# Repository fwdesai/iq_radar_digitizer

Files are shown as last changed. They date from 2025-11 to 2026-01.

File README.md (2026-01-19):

IQ radar digitizer board for vital signs monitoring

v1
Screenshot 2025-11-26 at 11 20 54 PM

v2
Screenshot 2025-11-26 at 11 20 23 PM

v2 board pictured with K-LC5 mm-wave singled ended module:
FullSizeRender (1)

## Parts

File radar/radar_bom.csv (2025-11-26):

Id | Designator | Footprint | Quantity | Designation | Supplier and ref
1 | C24,C23,C4,C25,C22,C3 | C_0603_1608Metric | 6 | 3.3n
2 | C15,C10,C20,C18,C21,C8,C6,C19,C9,C14,C11 | C_0603_1608Metric | 11 | 0.1u
3 | R14 | R_0603_1608Metric | 1 | 82k
4 | R3,R1,R4,R5,R2,R8,R15,R7 | R_0603_1608Metric | 8 | 1k
5 | J7 | PinHeader_1x05_P2.54mm_Vertical | 1 | Conn_01x05_Pin
6 | C28,C5 | C_0603_1608Metric | 2 | 1n
7 | R18,R19 | R_0603_1608Metric | 2 | 0
8 | C26 | C_0603_1608Metric | 1 | 10n
9 | J4,J1,J2,J3 | SMA_Amphenol_132289_EdgeMount | 4 | Conn_Coaxial
10 | U3,U4 | DFN-24-1EP_4x7mm_P0.5mm_EP2.64x6.44mm | 2 | LTC2508CDKD-32
11 | R9,R12,R11,R10 | R_0603_1608Metric | 4 | 10
12 | U1 | LFCSP-24-1EP_4x4mm_P0.5mm_EP2.5x2.5mm_ThermalVias | 1 | ADA4940-2
13 | C16,C7,C17,C27 | C_0603_1608Metric | 4 | 10u
14 | U5 | SOIC-8-1EP_3.9x4.9mm_P1.27mm_EP2.29x3mm | 1 | ~
15 | R16 | R_0603_1608Metric | 1 | 100k
16 | R6,R13 | R_0603_1608Metric | 2 | 10k
17 | C13,C12 | C_1210_3225Metric_Pad1.33x2.70mm_HandSolder | 2 | 47u
18 | C1,C2 | C_0603_1608Metric | 2 | 1u
19 | J5 | PinHeader_1x05_P2.54mm_Horizontal | 1 | Conn_01x05_Pin
20 | U2 | SOIC-8_3.9x4.9mm_P1.27mm | 1 | ~
21 | J6 | PinHeader_1x01_P2.54mm_Vertical | 1 | Conn_01x01_Pin
22 | A1 | RaspberryPi_Pico_Common_THT | 1 | RaspberryPi_Pico_W

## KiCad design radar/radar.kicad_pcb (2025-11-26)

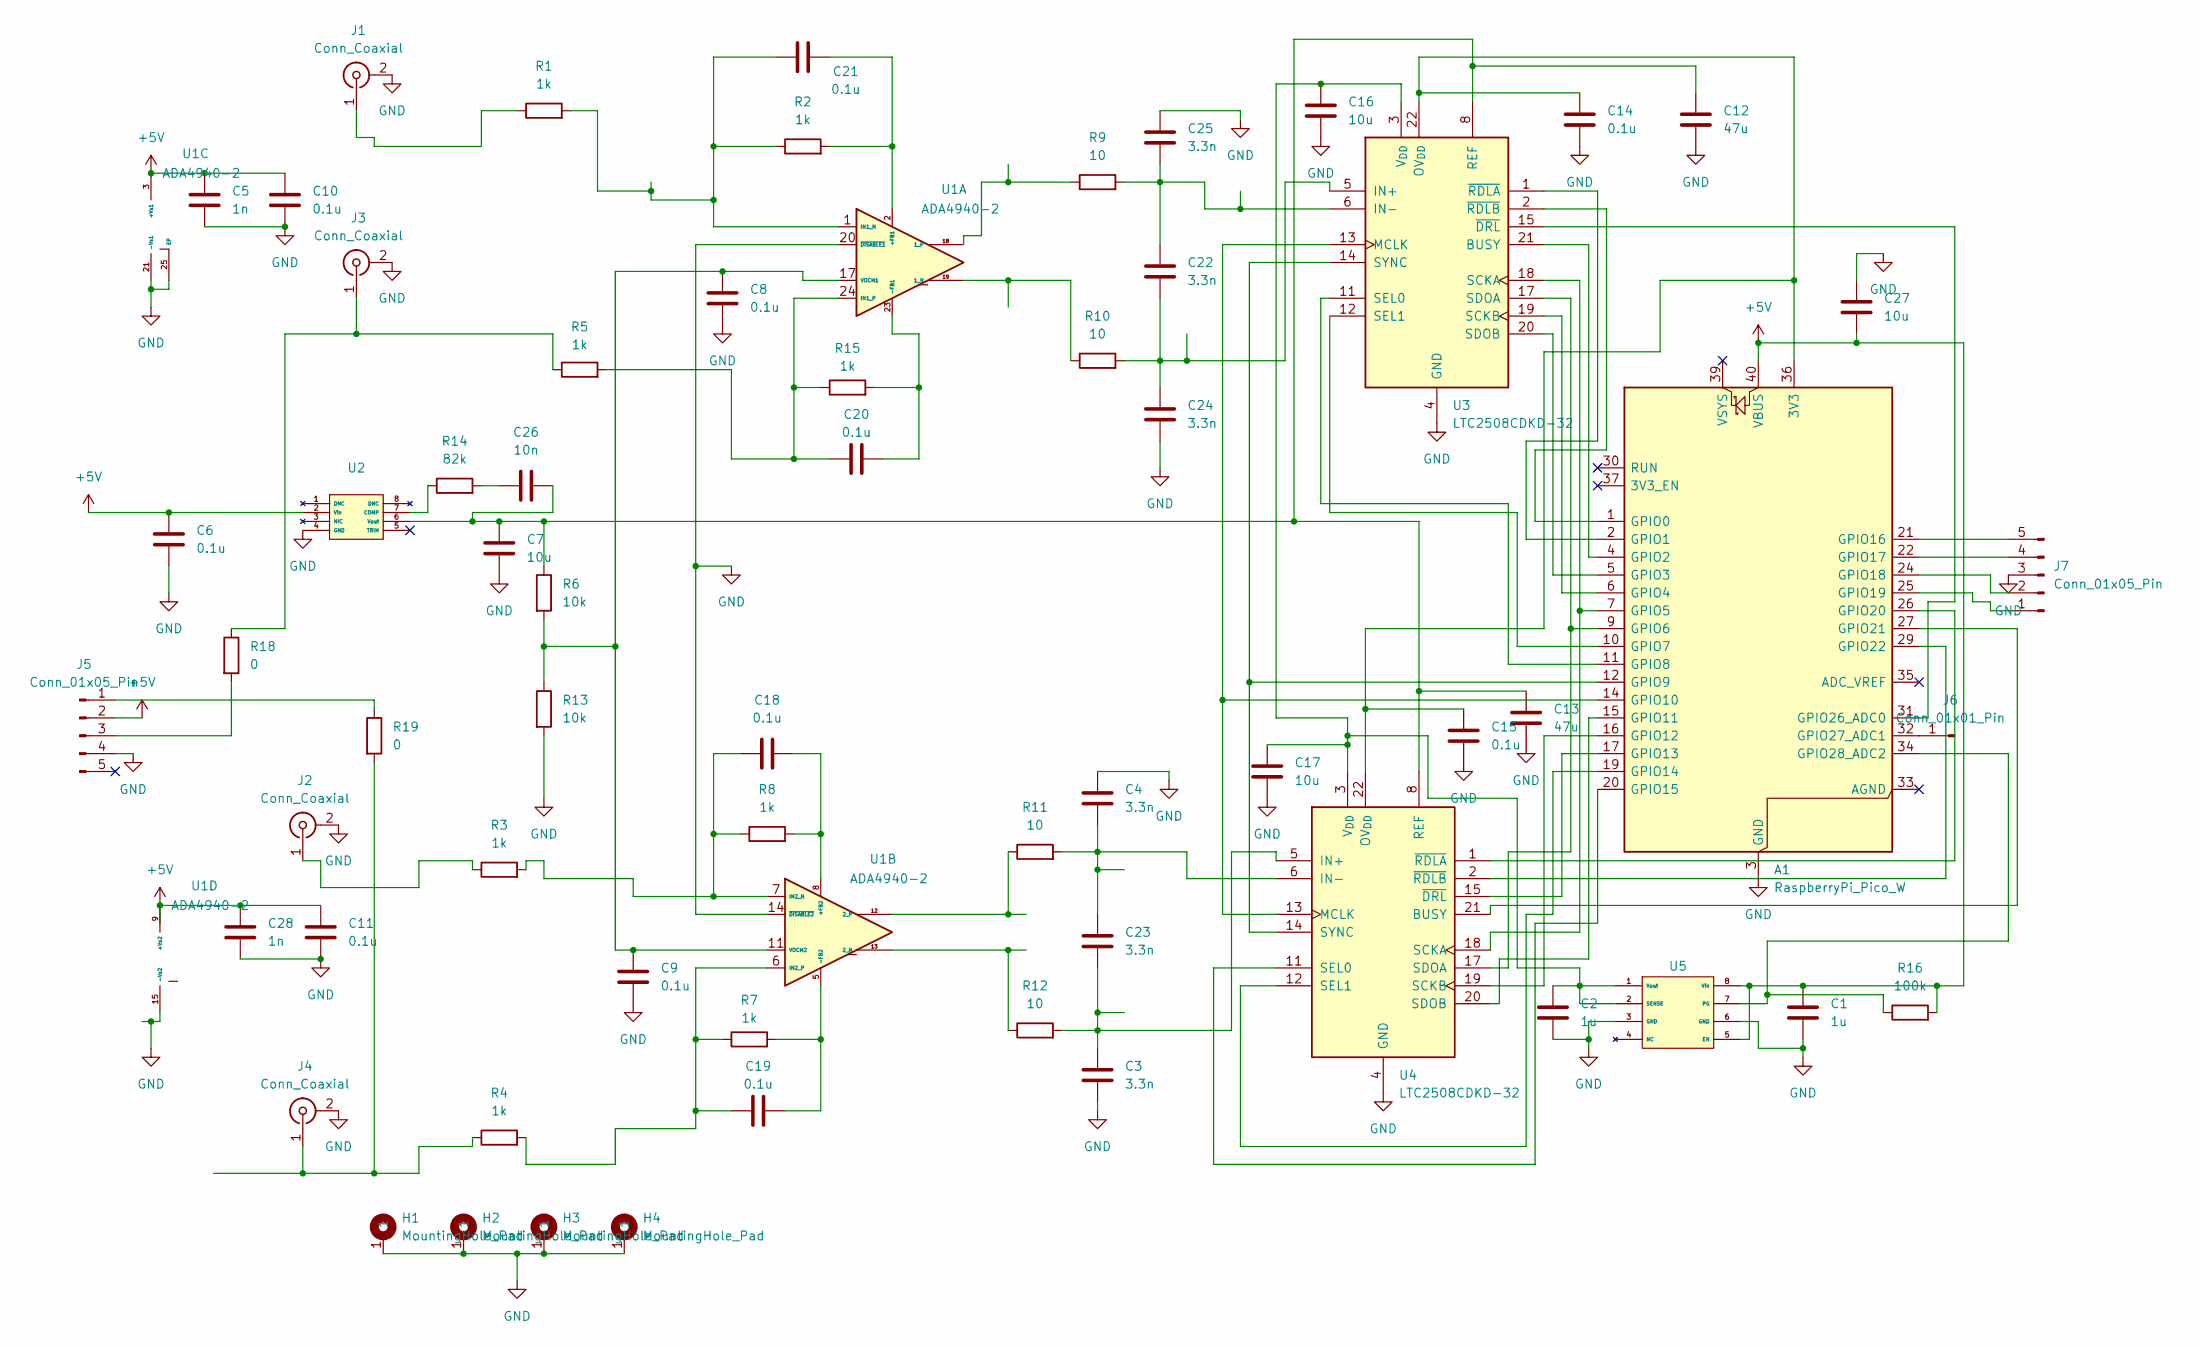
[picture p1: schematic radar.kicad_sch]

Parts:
A1: RaspberryPi_Pico_W; RaspberryPi_Pico_Common_THT
C1, C2: 1u; C_0603_1608Metric
C3, C4, C22, C23, C24, C25: 3.3n; C_0603_1608Metric
C5, C28: 1n; C_0603_1608Metric
C6, C8, C9, C10, C11, C14, C15, C18, C19, C20, C21: 0.1u; C_0603_1608Metric
C7, C16, C17, C27: 10u; C_0603_1608Metric
C12, C13: 47u; C_1210_3225Metric_Pad1.33x2.70mm_HandSolder
C26: 10n; C_0603_1608Metric
H1, H2, H3, H4: MountingHole_Pad; MountingHole_4.3mm_M4_Pad_Via
J1, J2, J3, J4: Conn_Coaxial; SMA_Amphenol_132289_EdgeMount
J5: Conn_01x05_Pin; PinHeader_1x05_P2.54mm_Horizontal
J6: Conn_01x01_Pin; PinHeader_1x01_P2.54mm_Vertical
J7: Conn_01x05_Pin; PinHeader_1x05_P2.54mm_Vertical
R1, R2, R3, R4, R5, R7, R8, R15: 1k; R_0603_1608Metric
R6, R13: 10k; R_0603_1608Metric
R9, R10, R11, R12: 10; R_0603_1608Metric
R14: 82k; R_0603_1608Metric
R16: 100k; R_0603_1608Metric
R18, R19: 0; R_0603_1608Metric
U1: ADA4940-2; LFCSP-24-1EP_4x4mm_P0.5mm_EP2.5x2.5mm_ThermalVias
U2: SOIC-8_3.9x4.9mm_P1.27mm
U3, U4: LTC2508CDKD-32; DFN-24-1EP_4x7mm_P0.5mm_EP2.64x6.44mm
U5: SOIC-8-1EP_3.9x4.9mm_P1.27mm_EP2.29x3mm

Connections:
+5V: A1.40 (VBUS), C1.1, C5.1, C6.1, C10.1, C11.1, C27.2, C28.1, J5.2, R16.2, U1.3 (+Vs1), U1.4 (+FB2), U1.9 (+Vs2), U1.10 (+FB2), U2.2 (Vin), U5.5 (EN), U5.8 (Vin)
unnamed: A1.36 (3V3), C14.1, C15.1, U3.22 (OV_{DD}), U4.22 (OV_{DD})
unnamed: A1.1 (GPIO0), U3.2 (~RDLB)
unnamed: A1.2 (GPIO1), U3.1 (~RDLA)
unnamed: A1.4 (GPIO2), U3.21 (BUSY)
unnamed: A1.5 (GPIO3), U3.20 (SDOB)
unnamed: A1.6 (GPIO4), U3.19 (SCKB)
unnamed: A1.7 (GPIO5), U3.18 (SCKA), U4.18 (SCKA)
unnamed: A1.9 (GPIO6), U3.17 (SDOA), U4.17 (SDOA)
unnamed: A1.10 (GPIO7), U3.12 (SEL1)
unnamed: A1.11 (GPIO8), U3.11 (SEL0)
unnamed: A1.12 (GPIO9), U3.14 (SYNC), U4.14 (SYNC)
unnamed: A1.14 (GPIO10), U3.13 (MCLK), U4.13 (MCLK)
unnamed: A1.15 (GPIO11), U4.20 (SDOB)
unnamed: A1.16 (GPIO12), U4.19 (SCKB)
unnamed: A1.17 (GPIO13), U4.15 (~DRL)
unnamed: A1.19 (GPIO14), U4.12 (SEL1)
unnamed: A1.20 (GPIO15), U4.11 (SEL0)
unnamed: A1.21 (GPIO16), J7.5
unnamed: A1.22 (GPIO17), J7.4
unnamed: A1.24 (GPIO18), J7.2
unnamed: A1.25 (GPIO19), J7.1
unnamed: A1.26 (GPIO20), U4.1 (~RDLA)
unnamed: A1.27 (GPIO21), U4.21 (BUSY)
unnamed: A1.31 (GPIO26_ADC0), U3.15 (~DRL)
unnamed: A1.32 (GPIO27_ADC1), J6.1
unnamed: A1.34 (GPIO28_ADC2), R16.1, U5.7 (PG)
unnamed: C26.1, R14.2
unnamed: J1.1 (In-), R1.1
unnamed: J2.1 (In), R3.1
unnamed: J3.1 (In+), R5.1, R18.1
unnamed: J4.1 (In), R4.1, R19.2
unnamed: J5.1, R19.1
unnamed: J5.3, R18.2
unnamed: R10.1, U1.19 (1_N)
unnamed: R9.1, U1.18 (1_P)
unnamed: C21.2, R2.2, U1.2 (+FB1)
unnamed: C20.2, R15.2, U1.23 (-FB1)
unnamed: C21.1, R1.2, R2.1, U1.1 (IN1_N)
unnamed: C20.1, R5.2, R15.1, U1.24 (IN1_P)
unnamed: C8.1, C9.1, R6.2, R13.1, U1.11 (VOCM2), U1.17 (VOCM1)
unnamed: R12.1, U1.13 (2_N)
unnamed: R11.1, U1.12 (2_P)
unnamed: C18.2, R8.2, U1.8 (+FB2)
unnamed: C19.2, R7.2, U1.5 (-FB2)
unnamed: C18.1, R3.2, R8.1, U1.7 (IN2_N)
unnamed: C19.1, R4.2, R7.1, U1.6 (IN2_P)
unnamed: R14.1, U2.7 (COMP)
unnamed: C7.1, C12.1, C13.1, C26.2, R6.1, U2.6 (Vout), U3.8 (REF), U3.9 (REF), U3.10 (REF), U4.8 (REF), U4.9 (REF), U4.10 (REF)
unnamed: C22.2, C24.1, R10.2, U3.5 (IN+)
unnamed: C22.1, C25.2, R9.2, U3.6 (IN-)
unnamed: C2.1, C16.1, C17.1, U3.3 (V_{DD}), U4.3 (V_{DD}), U5.1 (Vout), U5.2 (SENSE)
unnamed: C3.1, C23.2, R12.2, U4.5 (IN+)
unnamed: C4.2, C23.1, R11.2, U4.6 (IN-)

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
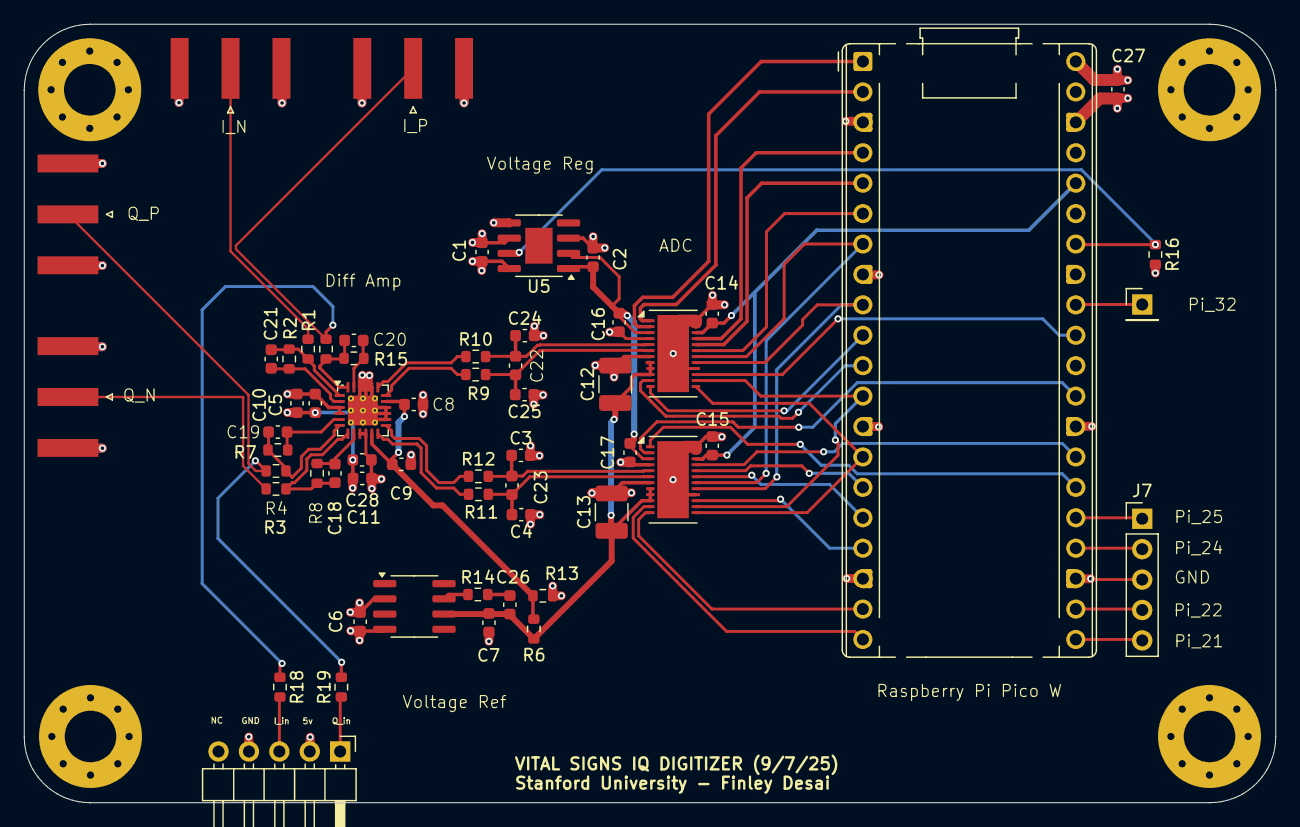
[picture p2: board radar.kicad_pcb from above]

Board: 4 copper layers, 104.5 x 65.0 mm, 63 parts (0 on the bottom side), 56 nets.

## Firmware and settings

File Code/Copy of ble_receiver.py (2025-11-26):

import asyncio
import struct
from bleak import BleakClient, BleakScanner
from collections import deque
import time


# BLE configuration - must match the transmitter
BLE_NAME = "iq_digitizer"
BLE_SVC_UUID = "0000181a-0000-1000-8000-00805f9b34fb"  # Environmental Sensing
BLE_CHARACTERISTIC_UUID = "00002a6e-0000-1000-8000-00805f9b34fb"  # Temperature
FILE = 'bt_bh_2.txt'


duration = 20
fs = 200000
decimation = 1024
N = int((fs / decimation) * duration * 2)

def to_signed(val, bits):
    """Convert unsigned integer to signed integer with given bit width."""
    if val & (1 << (bits - 1)):  # if sign bit is set
        val -= 1 << bits
    return val

class BLEDataReceiver:
    def __init__(self, max_buffer_size=10000):
        self.client = None
        self.data_buffer = deque(maxlen=max_buffer_size)
        self.is_connected = False
        self.receive_count = 0
        self.target_packets = N
        
    async def scan_for_device(self, timeout=80.0):
        """Scan for the BLE device by name"""
        print(f"Scanning for device '{BLE_NAME}'...")
        
        devices = await BleakScanner.discover(timeout=timeout)
        for device in devices:
            if device.name == BLE_NAME:
                print(f"Found device: {device.name} ({device.address})")
                return device
        
        print(f"Device '{BLE_NAME}' not found")
        return None
    
    def notification_handler(self, sender, data):
        """Handle incoming BLE notifications"""
        try:
            # Unpack little-endian signed integer
            if len(data) == 4:  # struct.pack('<i') creates 4 bytes
                val = struct.unpack('<i', data)[0]
                
                # Store only the integer value (negated)
                self.data_buffer.append(val * -1)
                
                self.receive_count += 1
                
                # Print every 100th packet to show activity
                if self.receive_count % 100 == 0:
                    print(f"Received {self.receive_count}/{self.target_packets} packets, latest value: {val * -1}")
            else:
                print(f"Unexpected data length: {len(data)} bytes")
                
        except Exception as e:
            print(f"Error processing notification: {e}")
    
    async def connect_and_receive(self):
        """Connect to device and start receiving data"""
        device = await self.scan_for_device()
        if not device:
            return False
        
        try:
            async with BleakClient(device.address) as client:
                self.client = client
                self.is_connected = True
                print(f"Connected to {device.name}")
                print(f"Target: {self.target_packets} packets")
                
                # Subscribe to notifications
                await client.start_notify(BLE_CHARACTERISTIC_UUID, self.notification_handler)
                print("Subscribed to notifications")
                start_time = time.time()
                
                # Keep receiving until we have N packets
                try:
                    while self.receive_count < self.target_packets:
                        await asyncio.sleep(0.1)
                        
                    end_time = time.time()
                    print(f"\nTarget of {self.target_packets} packets reached!")
                    print("Saving data automatically...")
                    print(f'Duration = {end_time - start_time}')
                
                except KeyboardInterrupt:
                    print("\nReceiving interrupted by user")
                
                finally:
                    # Stop notifications
                    await client.stop_notify(BLE_CHARACTERISTIC_UUID)
                    print("Stopped notifications")

                    # Always save data if we have any
                    if len(self.data_buffer) > 0:
                        self.save_data_to_file(FILE)
                    
        except Exception as e:
            print(f"Connection error: {e}")
            return False
        
        finally:
            self.is_connected = False
            print("Disconnected")
            
        return True
    
    def get_data_array(self):
        """Return received data as a list"""
        return list(self.data_buffer)
    
    def get_values_array(self):
        """Return the integer values as a list (same as get_data_array since we only store integers)"""
        return list(self.data_buffer)
    
    def clear_buffer(self):
        """Clear the data buffer"""
        self.data_buffer.clear()
        self.receive_count = 0
        print("Data buffer cleared")
    
    def save_data_to_file(self, filename="ble_data.txt"):
        """Save received data to a text file"""
        try:
            with open(filename, 'w') as f:
                for item in self.data_buffer:
                    f.write(str(item) + '\n')

            print(f"Data saved to {filename}")
            return True
            
        except Exception as e:
            print(f"Error saving data: {e}")
            return False









async def main():
    """Main function to run the receiver"""
    receiver = BLEDataReceiver(max_buffer_size=50000)
    
    print("BLE Data Receiver Starting...")
    print(f"Will collect {N} packets then automatically stop")
    print("Press Ctrl+C to stop early")
    
    try:
        success = await receiver.connect_and_receive()
        
        if success and len(receiver.data_buffer) > 0:
            print(f"\nReceived {len(receiver.data_buffer)} total packets")
            
            # Data was already saved automatically in connect_and_receive()
            print('Data automatically saved to received_ble_data.txt')
            
            # Example: Print first few packets
            print("\nFirst 5 packets:")
            for i, item in enumerate(list(receiver.data_buffer)[:5]):
                print(f"  {i+1}: value={item}")
            
            # Get just the values as an array
            values = list(receiver.data_buffer)
            print(f"Values array length: {len(values)}")
            if values:
                print(f"Value range: {min(values)} to {max(values)}")
        
    except KeyboardInterrupt:
        print("\nShutdown requested")
    
    except Exception as e:
        print(f"Error in main: {e}")

if __name__ == "__main__":
    asyncio.run(main())

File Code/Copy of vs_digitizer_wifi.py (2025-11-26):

import array, time
import machine
from machine import Pin
import rp2
from rp2 import PIO, StateMachine, asm_pio
import sys
import struct
import asyncio
import aioble
import bluetooth
import network
import usocket as socket
import time


# GPIO pins 16-19, 27 are free for other use
# Variables to set
###################################################################################
filtered_out = True
no_latency_out = False
data_out = 2                   # options 0 for write to file, 1 for bluetooth, 2 for wifi
FILE = 'test.txt'
data = open(FILE, 'w')

SSID = 'StanfordStudents'       # network name and password for wifi data transfer
PASSWORD = 'Wolfson1176'

decimation = 4096				# options here are 256, 1024, 4096, 16384 (ignore if filtered_out = 0)
duration = 20
###################################################################################
# LEAVE THESE VARIABLES UNCHANGED
fs = int(200e3)
N = (fs / decimation) * duration * 2
buffer = []


# PINS FOR THE INTERFACE WITH THE ADCs
RDLB_1 = Pin(0, Pin.OUT)
RDLA_1 = Pin(1, Pin.OUT)
BUSY_1 = Pin(2, Pin.IN)
SDOB_1 = Pin(3, Pin.IN)
SCKB_1 = Pin(4, Pin.OUT)
SCKA = Pin(5, Pin.OUT)
SDOA = Pin(6, Pin.IN)



SYNC = Pin(9, Pin.OUT)
MCLK = Pin(10, Pin.OUT)
SDOB_2 = Pin(11, Pin.IN)
SCKB_2 = Pin(12, Pin.OUT)
DRL_2 = Pin(13, Pin.IN, Pin.PULL_DOWN)

SEL1 = Pin(14, Pin.IN)
SEL0 = Pin(15, Pin.IN)

RDLA_2 = Pin(20, Pin.OUT)
BUSY_2 = Pin(21, Pin.IN)
RDLB_2 = Pin(22, Pin.OUT)
DRL_1 = Pin(26, Pin.IN, Pin.PULL_DOWN)

# POWER GOOD PIN ON THE REGULATOR
#PG_REG = Pin(28, Pin.IN)

# State Machine Frequency
sm_freq = int(100e6)

###################################################################################

################################## BLUETOOTH SETUP ################################
if (data_out == 1):
    print('Data out over bluetooth')
    # bluetooth setup code
    ble_name = "iq_digitizer"
    ble_svc_uuid = bluetooth.UUID(0x181A)
    print(ble_svc_uuid)
    ble_characteristic_uuid = bluetooth.UUID(0x2A6E)
    ble_appearance = 0x0300
    ble_advertising_interval = 300
    ble_service = aioble.Service(ble_svc_uuid)
    ble_characteristic = aioble.Characteristic(
        ble_service,
        ble_characteristic_uuid,
        read=True,
        notify=True)
    aioble.register_services(ble_service)
elif(data_out == 2):
# WIFI setup code here
    print('Data out over wifi')
    wlan = network.WLAN(network.STA_IF)
    wlan.active(True)
    wlan.connect(SSID, PASSWORD)

    while not wlan.isconnected():
        pass

    print('Connection')
    print('Wifi Connected')
    print(wlan.ifconfig()[0])

    server_socket = socket.socket(socket.AF_INET, socket.SOCK_DGRAM)
    server_socket.bind((wlan.ifconfig()[0], 12345))
    print('server is listening')

else:
    if (data_out != 0):
        print(f"The variable data_out is set to an invalid value of {data_out}. Please fix.\n")
        sys.exit()
    else:
        print('Data output to file')

async def ble_task():
    while True:
        async with await aioble.advertise(
            ble_advertising_interval,
            name=ble_name,
            services=[ble_svc_uuid],
            appearance=ble_appearance) as connection:
            print('Connection from', connection.device)
            sm5.active(1)
            sm0.active(1)
            sm2.active(1)
            sm3.active(1)
            sm1.active(1)
            
            # Start the data sending task
            try:
                await send_data(connection)
            finally:
                # Stop state machines when disconnected
                sm5.active(0)
                sm0.active(0)
                sm2.active(0)
                sm3.active(0)
                sm1.active(0)

async def send_data(connection):
    try:
        sample_count = 0
        while connection.is_connected():
            if not connection.is_connected():
                break
            val = sm1.get()  # This blocks until data is available
            
            if val is not None:
                # Pack as little-endian signed integer and notify client
                packet = struct.pack('<i', val)
                ble_characteristic.notify(connection, packet)
                sample_count += 1
                
            else:
                print("Warning: sm1.get() returned None")
                await asyncio.sleep_ms(1)  # Small delay if no data
                
    except Exception as e:
        print(f"send_data error: {e}")


            
async def main():
    task1 = asyncio.create_task(ble_task())
    await task1


###################################################################################


if (filtered_out == no_latency_out):
    print('Please choose only 1 of filtered_out and no_latency_out')
    
if (filtered_out and not no_latency_out):
    print('filtered')
    RDLB_1.value(1)
    RDLB_2.value(1)
    #RDLA_1.value(0)
    #RDLA_2.value(0)
elif (not filtered_out and no_latency_out):
    print('no latency output')
    RDLA_1.value(1)
    RDLA_2.value(1)
    #RDLB_1.value(0)
    #RDLB_2.value(0)


#Set the decimation for the ADCs based on the decimation variable above
###################################################################################
if decimation == 256:
    print('in 256')
    pass
elif decimation == 1024:
    print('in 1024')
    pass
elif decimation == 4096:
    print('in 4096')
    pass
elif decimation == 16384:
    print('in 16384')
    pass
else:
    print(f'{decimation} is an invalid entry for the decimation variable. Please correct if you intend do use the filtered ouput')
    if filtered_out:
        print('Program terminating')
        sys.exit()
###################################################################################

if filtered_out:
    print(f'Using the filtered output with decimation factor of {decimation}.')
else:
    print('Using the no latency ouput.')



############################## STATE MACHINE FUNCTIONS ############################
# MCLK Function
@rp2.asm_pio(set_init=PIO.OUT_LOW)
def sync_mclk():
    #inital sync pulse
    #set(pins, 0b01)
    #nop() [1]
    #set(pins, 0b00)
    
    wrap_target()
    
    set(pins, 1)
    nop() [4]
    set(pins, 0)
    
    
    nop()		[31]
    nop()		[31]
    nop()		[31]
    nop()		[31]
    nop()		[31]
    nop()		[31]
    nop()		[31]
    nop()		[31]
    nop()		[31]
    nop()		[31]
    nop()		[31]
    nop()		[31]
    nop()		[31]
    nop()		[31]
    nop() 		[31]
    nop()		[12]
    
    wrap()
    

# DRL Function
# using drl from ADC 2, ie gpio 13
@rp2.asm_pio(set_init=PIO.OUT_LOW)
def sync_drl():
    wrap_target()
    wait(1, pin, 0)
    wait(0, pin, 0)
    irq(0)
    set(pins, 1) [2]
    set(pins, 0)
    wrap()
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
